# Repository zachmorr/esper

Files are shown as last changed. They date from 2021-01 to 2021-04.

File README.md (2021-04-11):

# This Project has moved!

It can now be [found here](https://github.com/openesper/esper).

This repo is just kept so history is still available

Imgur

# About Esper

Heavily inspired by the [Pi-Hole](https://github.com/pi-hole/pi-hole), this project aims to bring network wide ad-blocking to another popular device popular among makers and hobbyists, the ESP32.

## What is DNS?

Commonly referred to as the "phone book for the internet", the DNS protocol is how devices map human readable urls like google.com or facebook.com into IP addresses that the device can use.

## How does Esper block ads?

Just like the [Pi-Hole](https://github.com/pi-hole/pi-hole), Esper acts as a DNS server for devices. When sent a DNS query, Esper will read the url the device is requesting, then decide to block the request by returning 0.0.0.0 or forward the request on to a real DNS server.

## Differences between Pi-hole and Esper

The biggest, and most obvious difference is the hardware these projects run on. Pi-hole aims to be available on any Linux powered hardware, while Esper is an ESP32 specific project. Due to being run on a microcontroller, Esper is much more limited in it's capabilities and is therefore much more minimal in it's design.

## Why choose Esper instead of Pi-hole?

Choose whatever one suits you! If you like tinkering with hardware, and do not have much experience with the Raspberry Pi/Linux ecosystem, setting up the Esper software on an ESP32 dev board might be an interesting project. And while Esper may not be nearly as powerful as a Raspberry Pi, DNS protocol is very lightweight in nature. Unless you are in a household with 10+ people that are always online you will likely never going to need more computing power than a microcontroller can provide.

At the same time, if you have no problem using a shell and Linux environment, the Pi-hole is a much more feature rich and powerful piece of software that is a joy to use.

## How can I get an Esper?

The easiest way, is to purchase a pre-made one from the Tindie store. (Link incoming...) 

If you have some ESP32 development boards collecting dust, it will work on those too! It will take some slight configuration ([see instructions here](https://github.com/zachmorr/esper/blob/main/software/README.md)), but you can have it running in no time.

DISCLAIMER: It is **heavily** recommended to use a device with ethernet. Even the best Wifi will significantly increase latency and decrease reliability compared to a good copper connection.

If you want to try you hand an making an Esper from scratch, the hardware directory contains all the schematic, pcb, and enclosure files needed to build one yourself.

## Reprogramming Esper

Do you like the Esper hardware, but want to use it for something other than ad-blocking? Great! The Esper hardware is completely reprogrammable and includes an on-board USB-UART converter, no extra programmers are needed!

# Esper Development

## Tools Used

* KiCAD	- EDA tool used to design PCB
* FreeCAD - 3D modeling tool for designing enclosure
* Hugo - Static website generator used for embedded Esper website
* ESP-IDF - Contains ESP32 API and build tools for firmware development
* Python 3.7 - Scripts to glue everything together

## Directory Structure

    ├── hardware                    # Hardware root directory
    │   ├── custom components           # Custom KiCad component files
    │   ├── enclosure                   # FreeCAD project and STL files for enclosure
    │   ├── product                     # KiCad projects for Esper
    │   │   ├── usb-programmable        	# Includes CP2102 for easy usb programming
    │   │   └── jtag-header             	# 10-pin header for JTAG & UART, meant to be used with programmer
    │   └── programmer                  # KiCad project for programmer/debugger
    └── software                    # Software root directory
        ├── default blacklist           # List of URLs that will be blocked by default
        ├── firmware                    # ESP-IDF project that contains all code for Esper
        ├── scripts                     # Scripts used in build process and testing
        ├── tests                       # Scripts used in testing (not started yet)
        └── website                     # Hugo project used to generate website

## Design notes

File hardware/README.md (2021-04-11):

PCB

# Esper Hardware Design

## Goals

All Esper hardware is designed to be as easy to modify and manufacture as possible.

### PCB & Schematic

KiCAD is the obvious choice for EDA since it is free and has a large community support.

### Manufacturing

The Esper device is designed to be manufactured and assembled at JLCPCB. At low quantities (5-10 boards), no other board house that I've found comes close on price and ease of use.

This may change in the future if other companies start matching JLCPCB in price, or if I need to start manufacturing Esper at higher quantities.

### Part Selection

To make the process of manufacturing and assembly as easy as possible, all components (except connectors) are chosen from the [JLCPCB parts library](https://jlcpcb.com/parts). This means that connectors are the only parts that need to be hand soldered, but JLC recently added connectors to their parts library so this may change soon.

Also, in order to minimize the amount of work needed to keep custom schematic symbols and footprints up-to-date, it was a priority to minimize the amount of custom components and only use parts found in the default KiCAD library. Almost every part in the project has footprints and symbols included in KiCAD, or has an equivalent component included.

### Layers

Esper was originally designed to be two layers, but it ended up being far too much routing work for small savings in price so it was changed to be four layers.

### Enclosure

There are many 3D modeling tools out there, to varying degrees of free-ness, but I am not qualified to go over the pros and cons of each. FreeCAD was chosen for this project simply because it seemed to be the most popular open-source program, but I am sure almost any would work.

The enclosure is currently designed to be 3D printed, but alternatives are being looked into.

## BOM

To fully assemble an Esper, these parts are needed:

| Part | Quantity |
| --- | --- |
| Enclosure Top | 1 |
| Enclosure Bottom | 1 |
| Enclosure Dome | 1 |
| Esper PCBA | 1 |
| [Heat-Set Inserts (M2 x 0.4mm) x 2.5mm](https://www.mcmaster.com/catalog/127/3973) | 2 |
| [Screws (M2 x 0.4mm) x 6mm](https://www.mcmaster.com/catalog/127/3251) | 2 |

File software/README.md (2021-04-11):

Esper

# Esper Software

## Installation

### Arduino

At the moment there is no support for the Arduino environment yet, but it is being worked on.

### Requirements

In order to build and flash Esper, you will first need to [install ESP-IDF](https://docs.espressif.com/projects/esp-idf/en/latest/esp32/get-started/#installation-step-by-step) then [set up the environment variables](https://docs.espressif.com/projects/esp-idf/en/latest/esp32/get-started/index.html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).

### Configuration

If you are not using the Esper hardware, you will need to configure the project for your device. To do this, run 

    cd esper/software/firmware
    idf.py menuconfig

Then configure the options under Application Configuration to match your device's capabilities.

### Building & Flashing

After installing ESP-IDF, build and flash your device by running these commands.

    cd esper/software/firmware
    idf.py build
    idf.py -p PORT [-b BAUD] flash

### Monitoring

If logging is enabled in your build, you can monitor the device while it is connected to your PC with this command

    idf.py -p PORT monitor

### Issues

If you have any issues, [this section](https://docs.espressif.com/projects/esp-idf/en/latest/esp32/get-started/index.html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) may be able to help.

### Website & Blacklist

If any changes are made to the website or blacklist in their respective directories, you will have to run the reformat scripts in the Scripts folder in order for the changes to be put into the build.
Examples of running the scripts can be seen in the build.sh script

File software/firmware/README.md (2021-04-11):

# Esper Firmware

This is an ESP-IDF project, written entirely in C. For an explination of the project structure and files, [the espressif docs](https://docs.espressif.com/projects/esp-idf/en/latest/esp32/api-guides/build-system.html) are a good place to start.

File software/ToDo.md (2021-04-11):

## TODO:

### Version 0.1
- Make LED blink when blocking
- Run through tests
- Set up Tindie
    - Packaging?
- How to use guide
- Basic site at openesper.com
- Push to official repo

### Tests:
- Start writing test doc
- Start incorporating unit testing
### Build
- Add Arduino support
### Web
- Password authentication
- Respond to POST requests with current results
- Analytics
    - Total queries and total blocked queries
    - most blocked/queried websites
- show currently connected network & ip
- show connected clients
- Add log page select to homepage 
- Upload/download blacklist files
- advanced settings fold
### Debugging
- Add debug page to website
- Add errors to error log
- remaining memory
    - total and for each task
### OTA Updates
- progress bar
### DATETIME
- Add timezone select
- Connect to SNTP in background, non-blocking
### CONFIGURATION
- Look into wifi_provisioning library
### DNS
- Support for non A/AAAA types
- better client handling
    - print error if client never got response
- Reverse DNS support
- Benchmark DNS response times
### LEDs
- LED Error Codes
### BLACKLIST
- more error handling errors
- Benchmark speed improvement from keeping blacklist in RAM instead of flash
### FLASH
- figure out way to emulate flash wear out & error handling
- Handle flash errors
- Document what is being held in flash

## Maybe Some Day:
- DHCP support
    - Individual block lists for devices
    - User accounts??
- DNS Over HTTPS (early tests dont look hopeful for ESP32, will likely need MPU)

## Known Bugs:
- Logging breaks under high bandwidth (~25 queries per second)
- Throws "emac_esp32: no mem for receive buffer" at high bandwidth 
- Does not respond to queries with 'Additional Sections' (aka dig) correctly
- Does not repond to reverse lookups correctly
- Have to reset device if network ssid/pass change
- black/whitelist buttons on homepage do not update after being added

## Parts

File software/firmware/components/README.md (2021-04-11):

# Directory of all components used in project

### Datetime

Used to get time from SNTP server

### DNS

All DNS related activities are in here. This is where the socket, listening on port 53, is created and then parses any packets it receives.

### Error

This is where the ERROR_CHECK macro, as well as most errors are defined. 

### Events

This component keeps track of the current state of the module using a FreeRTOS event group. 
Any component get set/clear/check any of the event bits at any time.

### Flash

All methods that retreive data from flash are located in this component. It stores blacklist, settings, and logging data to be retreived by other components.

### GPIO

LED and button functions. LED task it notified any time the current state of the device is changed and updates accordingly.

### HTTP

This is the largest component. It stores all the code for both the application and configuration websites.

### Logging

The logging task is in here. The task is notified any time a DNS query is made and then adds it's data to the log file.

### NetIF

Ethernet and Wifi code. Not used much after device is initialized and running.

### OTA

Over-The-Air updates. This contains the tasks that periodically check for updates and then writes the new update to flash.

### URL

Slightly confusing name, this is where the blacklist is kept. All functions that relate to the blacklist as well as url parsing are in here.

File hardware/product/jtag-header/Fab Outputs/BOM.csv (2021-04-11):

Comment | Designator | Footprint | LCSC
1uF | C1,C4,C9 | Capacitor_SMD:C_0402_1005Metric | C52923
10uF | C3,C10 | Capacitor_SMD:C_0805_2012Metric | C15850
0.1uF | C2,C5,C6,C7,C8,C11 | Capacitor_SMD:C_0402_1005Metric | C1525
GRN | D1 | Diode_SMD:D_0603_1608Metric | C72043
RS-3535MWAR | D2 | LED_SMD:LED_RGB_PLCC-6 | C110402
Ferrite_Bead | FB2 | Inductor_SMD:L_0805_2012Metric | C1015
MountingHole | H1,H2 | MountingHole:MountingHole_2.2mm_M2_Pad
USB_B_Micro | J1 | Connector_USB:USB_Micro-B_Molex-105017-0001
Conn_02x05_Odd_Even | J2 | EsperFootprints:CNC_3220-10-0100-00
RJ45_Amphenol_RJMG1BD3B8K1ANR | J3 | Connector_RJ:RJ45_Amphenol_RJMG1BD3B8K1ANR
2N7002 | Q1,Q2,Q3 | Package_TO_SOT_SMD:SOT-23 | C8545
470 | R1 | Resistor_SMD:R_0402_1005Metric | C25117
10K | R2,R8,R10,R11,R12,R24 | Resistor_SMD:R_0402_1005Metric | C25744
270 | R17,R21 | Resistor_SMD:R_0603_1608Metric | C22966
12.1K | R23 | Resistor_SMD:R_0402_1005Metric | C25852
47 | R3,R4 | Resistor_SMD:R_0603_1608Metric | C23182
82 | R5 | Resistor_SMD:R_1206_3216Metric | C247183
49.9 | R6,R7,R9,R13,R14,R15,R16,R18,R19,R20,R22 | Resistor_SMD:R_0402_1005Metric | C25120
PTS645VH83-2 LFS | SW1 | Button_Switch_THT:SW_Tactile_SPST_Angled_PTS645Vx83-2LFS
AZ1117EH-3.3TRG1 | U1 | Package_TO_SOT_SMD:SOT-223 | C108494
ESP32-WROOM-32E | U2 | RF_Module:ESP32-WROOM-32 | C701341
LAN8720A | U3 | Package_DFN_QFN:QFN-24-1EP_4x4mm_P0.5mm_EP2.6x2.6mm_ThermalVias | C45223

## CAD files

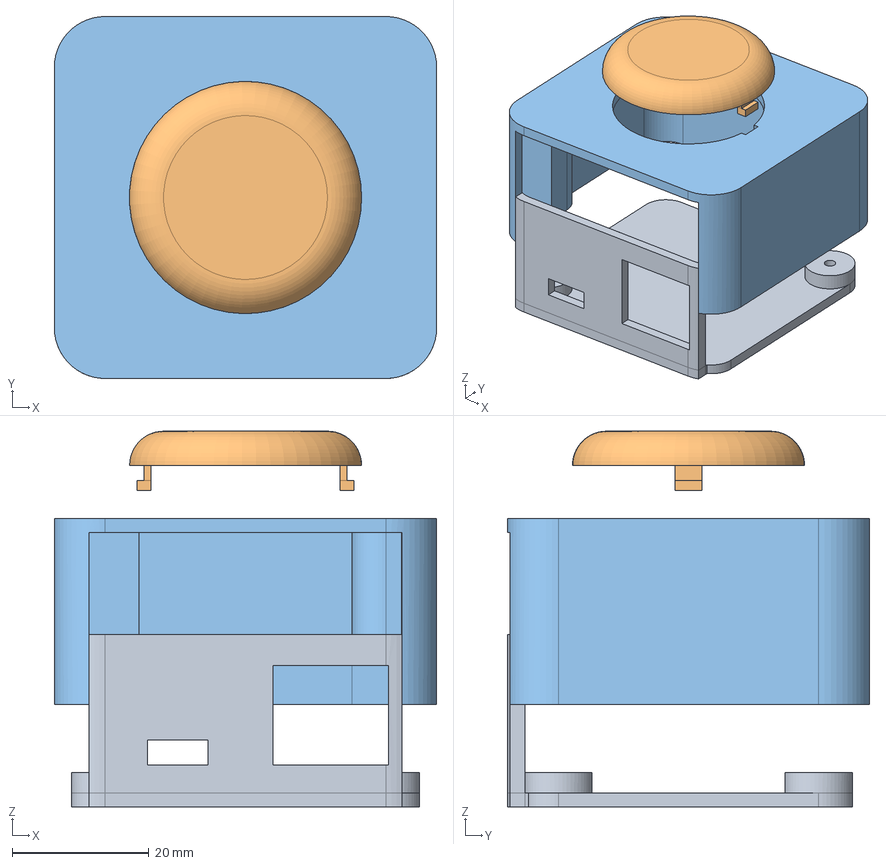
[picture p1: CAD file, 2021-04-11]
hardware/enclosure/Enclosure.FCStd
56.0 x 53.0 x 55.0 mm
Enclosure Bottom
Enclosure Dome
Enclosure Top

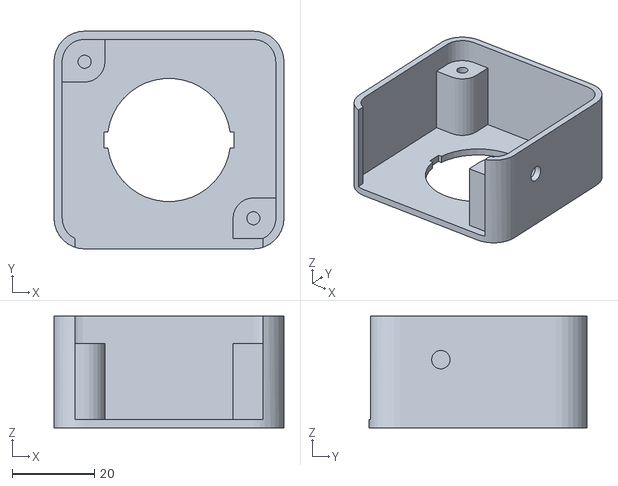
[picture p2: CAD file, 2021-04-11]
hardware/enclosure/EnclosureTop.stl
56.0 x 53.0 x 27.2

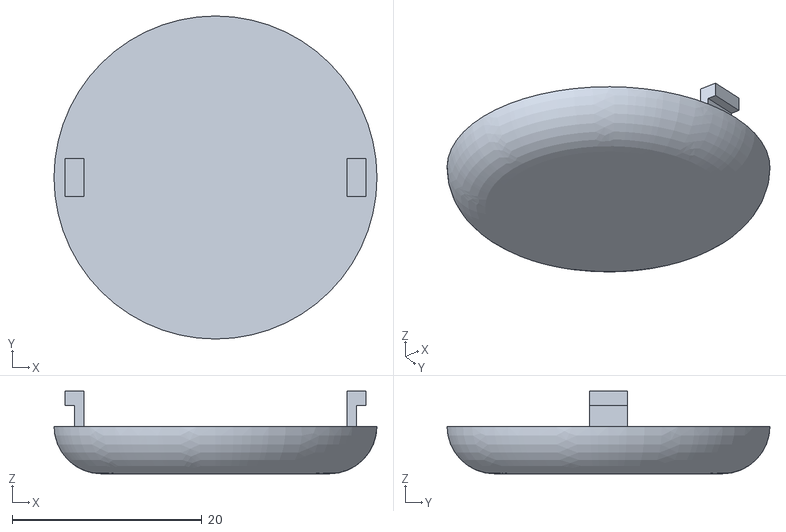
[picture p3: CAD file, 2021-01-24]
hardware/enclosure/EnclosureDome.stl
34.0 x 34.0 x 8.70

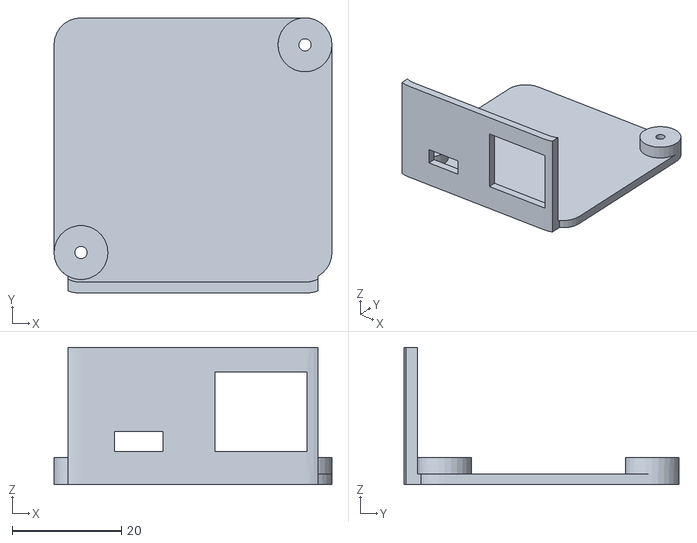
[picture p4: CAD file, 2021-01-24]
hardware/enclosure/EnclosureBottom.stl
51.0 x 50.5 x 25.2

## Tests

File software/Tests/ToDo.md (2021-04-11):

## Tests

### Initialization
1. LED is showing correct color during startup
2. Interfaces are initialized correctly, according to build options
3. Blocklists are successfully loaded in RAM
4. Logging file is opened
5. Webserver is initialized
6. LED is changed after initialization if finished

### Provisioning
1. Skip provisioning if wifi is disabled
2. Scan is started at boot
3. New scan is started when scan button is pressed
4. Error returned if ssid/pass is invalid
5. Connection successful if ssid/pass is valid
6. Ethernet saves IP if wifi is disabled and provisioning is skipped
7. Correct LED color is shown during provisioning

### Startup
1. Time is correctly received via SNTP 
2. Sockets created and listening on port 53
3. Webserver changes from provisioning to application correctly
4. Successfully checks for update at startup

### SNTP
1. Gets time from server and saves it to memory
2. Sets time to default value if SNTP server cant be reached
    - Continue to poll server if it fails
3. Changing timezone successfully updates current time

### DNS
1. Socket is created and listens for UDP packets on port 53
2. Packets larger than 512 bytes do not cause error
3. All DNS packets are forwarded if blocking is turned off
4. Packets that are not 'A' or 'AAAA' are forwarded
5. Responses from DNS server are successfully forward to correct client
6. DNS packets are 'blocked' if qname is in blacklist
7. DNS packets are 'captured' if provisioning is enabled or is qname matches device url

### GPIO
1. LEDs turn on and are correct colors
2. Pressing button toggles blocking state
3. Holding button for 5 seconds resets device
4. Holding button for 10 seconds rolls back to previous version

### Logging
1. DNS packets are logged successfully

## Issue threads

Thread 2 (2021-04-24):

lan8720: lan8720_init(411): wrong chip ID

gustavo-luz, 2021-04-24:
Was getting this error:
```
CMake Error at run_serial_tool.cmake:50 (message):
  /home/gustavo/.espressif/python_env/idf4.4_py3.8_env/bin/python
  /home/gustavo/esp/esp-idf/components/esptool_py/esptool/esptool.py --chip
  esp32 failed

make[3]: *** [CMakeFiles/flash.dir/build.make:57: CMakeFiles/flash] Error 1
make[2]: *** [CMakeFiles/Makefile2:2266: CMakeFiles/flash.dir/all] Error 2
make[1]: *** [CMakeFiles/Makefile2:2273: CMakeFiles/flash.dir/rule] Error 2
make: *** [Makefile:203: flash] Error 2
make failed with exit code 2
```
then i ran ```sudo chmod -R 777 /dev/ttyUSB0``` and was able to flash and write with no problems.

after that i started to have the following error at final step of   ```idf.py -p /dev/ttyUSB0 monitor```

```
E (851) lan8720: lan8720_init(411): wrong chip ID
E (851) esp_eth: esp_eth_driver_install(196): init phy failed
E (851) ETH: esp_eth_driver_install(&config, eth_handle) (ESP_FAIL)(FFFFFFFF)
E (851) IP: init_eth_handle(&eth_handle) (ESP_FAIL)(FFFFFFFF)
E (861) APP_BOOT: initialize_interfaces() (ESP_FAIL)(FFFFFFFF)
I (871) APP_BOOT: Starting provisioning...
I (871) IP: Turning Accesspoint on
E (881) IP: esp_wifi_set_mode(WIFI_MODE_APSTA) (ESP_ERR_WIFI_NOT_INIT)(3001)
E (881) APP_BOOT: turn_on_accesspoint() (ESP_FAIL)(FFFFFFFF)
I (891) APP_BOOT: Starting application...
I (891) IP: Starting interfaces
E (901) esp_eth: esp_eth_start(254): ethernet driver handle can't be null
E (911) IP: esp_eth_start(eth_handle) (ESP_ERR_INVALID_ARG)(102)
E (911) APP_BOOT: start_interfaces() (ESP_FAIL)(FFFFFFFF)
```

any clues ?

zachmorr, 2021-04-24:
What hardware is this on? Are you using a board with Ethernet? The lan8720 is an ethernet PHY, so if you are using a different PHY or no PHY you may get this error.

zachmorr, 2021-04-24:
If you are using a board without Ethernet, try disabling Ethernet in menuconfig, under application settings. Then run idf.py erase_flash; idf.py flash monitor;

gustavo-luz, 2021-04-25:
Its on nodemcu espwroom32, no ethernet. will try that, thanks

Closed 2021-04-28.

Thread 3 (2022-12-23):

Failed to resolve component 'littlefs' while running idf menuconfig or build commands

syedautherabbas, 2022-12-23:
syed@syeds-ubuntu:~/pihole/esper/software/firmware$ idf.py erase-flash
Executing action: erase-flash
Running cmake in directory /home/syed/pihole/esper/software/firmware/build
Executing "cmake -G Ninja -DPYTHON_DEPS_CHECKED=1 -DESP_PLATFORM=1 -DCCACHE_ENABLE=0 /home/syed/pihole/esper/software/firmware"...
-- IDF_TARGET not set, using default target: esp32
-- Found Git: /usr/bin/git (found version "2.37.2")
-- Component directory /home/syed/pihole/esper/software/firmware/components/littlefs does not contain a CMakeLists.txt file. No component will be added
-- The C compiler identification is GNU 8.4.0
-- The CXX compiler identification is GNU 8.4.0
-- The ASM compiler identification is GNU
-- Found assembler: /home/syed/.espressif/tools/xtensa-esp32-elf/esp-2021r2-8.4.0/xtensa-esp32-elf/bin/xtensa-esp32-elf-gcc
-- Detecting C compiler ABI info
-- Detecting C compiler ABI info - done
-- Check for working C compiler: /home/syed/.espressif/tools/xtensa-esp32-elf/esp-2021r2-8.4.0/xtensa-esp32-elf/bin/xtensa-esp32-elf-gcc - skipped
-- Detecting C compile features
-- Detecting C compile features - done
-- Detecting CXX compiler ABI info
-- Detecting CXX compiler ABI info - done
-- Check for working CXX compiler: /home/syed/.espressif/tools/xtensa-esp32-elf/esp-2021r2-8.4.0/xtensa-esp32-elf/bin/xtensa-esp32-elf-g++ - skipped
-- Detecting CXX compile features
-- Detecting CXX compile features - done
-- Building ESP-IDF components for target esp32
CMake Error at /home/syed/matter/tools/esp-idf/tools/cmake/build.cmake:200 (message):
  Failed to resolve component 'littlefs'.
Call Stack (most recent call first):
  /home/syed/matter/tools/esp-idf/tools/cmake/build.cmake:231 (__build_resolve_and_add_req)
  /home/syed/matter/tools/esp-idf/tools/cmake/build.cmake:232 (__build_expand_requirements)
  /home/syed/matter/tools/esp-idf/tools/cmake/build.cmake:232 (__build_expand_requirements)
  /home/syed/matter/tools/esp-idf/tools/cmake/build.cmake:512 (__build_expand_requirements)
  /home/syed/matter/tools/esp-idf/tools/cmake/project.cmake:378 (idf_build_process)
  CMakeLists.txt:8 (project)

abejfehr, 2022-12-29:
This happened to me, the components/littlefs folder was empty so I had to `git submodule update --init` in it

rBazan98, 2023-09-06:
> This happened to me, the components/littlefs folder was empty so I had to `git submodule update --init` in it

I had the same problem too. The components/littlefs directory contains yet another "commit-referenced" folder, components/littlefs/src/littlefs, so you need to run `git submodule update --init --recursive`

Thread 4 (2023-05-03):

Errors and warnings while building the project

NatDevzl, 2023-05-03:
When building the project, I encounter the following errors and warnings:

Executing action: all (aliases: build)
Running ninja in directory c:\users\nat\documents\esper\software\firmware\build
Executing "ninja all"...
[57/903] Generating ../../partition_table/partition-table.binPartition table binary generated. Contents:
*******************************************************************************
# ESP-IDF Partition Table
# Name, Type, SubType, Offset, Size, Flags
nvs,data,nvs,0x9000,16K,
otadata,data,ota,0xd000,8K,
phy_init,data,phy,0xf000,4K,
ota_0,app,ota_0,0x10000,1152K,
ota_1,app,ota_1,0x130000,1152K,
spiffs,data,spiffs,0x250000,1728K,
*******************************************************************************
[846/903] Building C object esp-idf/littlefs/CMakeFiles/__idf_littlefs.dir/src/littlefs_api.c.objFAILED: esp-idf/littlefs/CMakeFiles/__idf_littlefs.dir/src/littlefs_api.c.obj
ccache C:\Users\Nat\.espressif\tools\xtensa-esp32-elf\esp-2022r1-11.2.0\xtensa-esp32-elf\bin\xtensa-esp32-elf-gcc.exe  -IC:/Users/Nat/Documents/esper/software/firmware/build/config -IC:/Users/Nat/Documents/esper/software/firmware/components/littlefs/src -IC:/Users/Nat/Documents/esper/software/firmware/components/littlefs/include -IC:/Users/Nat/esp/components/newlib/platform_include -IC:/Users/Nat/esp/components/freertos/FreeRTOS-Kernel/include -IC:/Users/Nat/esp/components/freertos/esp_additions/include/freertos -IC:/Users/Nat/esp/components/freertos/FreeRTOS-Kernel/portable/xtensa/include -IC:/Users/Nat/esp/components/freertos/esp_additions/include -IC:/Users/Nat/esp/components/esp_hw_support/include -IC:/Users/Nat/esp/components/esp_hw_support/include/soc -IC:/Users/Nat/esp/components/esp_hw_support/include/soc/esp32 -IC:/Users/Nat/esp/components/esp_hw_support/port/esp32/. -IC:/Users/Nat/esp/components/esp_hw_support/port/esp32/private_include -IC:/Users/Nat/esp/components/heap/include -IC:/Users/Nat/esp/components/log/include -IC:/Users/Nat/esp/components/soc/include -IC:/Users/Nat/esp/components/soc/esp32/. -IC:/Users/Nat/esp/components/soc/esp32/include -IC:/Users/Nat/esp/components/hal/esp32/include -IC:/Users/Nat/esp/components/hal/include -IC:/Users/Nat/esp/components/hal/platform_port/include -IC:/Users/Nat/esp/components/esp_rom/include -IC:/Users/Nat/esp/components/esp_rom/include/esp32 -IC:/Users/Nat/esp/components/esp_rom/esp32 -IC:/Users/Nat/esp/components/esp_common/include -IC:/Users/Nat/esp/components/esp_system/include -IC:/Users/Nat/esp/components/esp_system/port/soc -IC:/Users/Nat/esp/components/esp_system/port/include/private -IC:/Users/Nat/esp/components/xtensa/include -IC:/Users/Nat/esp/components/xtensa/esp32/include -IC:/Users/Nat/esp/components/lwip/include -IC:/Users/Nat/esp/components/lwip/include/apps -IC:/Users/Nat/esp/components/lwip/include/apps/sntp -IC:/Users/Nat/esp/components/lwip/lwip/src/include -IC:/Users/Nat/esp/components/lwip/port/esp32/include -IC:/Users/Nat/esp/components/lwip/port/esp32/include/arch -IC:/Users/Nat/esp/components/spi_flash/include -mlongcalls -Wno-frame-address  -fdiagnostics-color=always -ffunction-sections -fdata-sections -Wall -Werror=all -Wno-error=unused-function -Wno-error=unused-variable -Wno-error=deprecated-declarations -Wextra -Wno-unused-parameter -Wno-sign-compare -Wno-enum-conversion -gdwarf-4 -ggdb -Og -fmacro-prefix-map=C:/Users/Nat/Documents/esper/software/firmware=. -fmacro-prefix-map=C:/Users/Nat/esp=/IDF -fstrict-volatile-bitfields -Wno-error=unused-but-set-variable -fno-jump-tables -fno-tree-switch-conversion -DconfigENABLE_FREERTOS_DEBUG_OCDAWARE=1 -std=gnu17 -Wno-old-style-declaration -D_GNU_SOURCE -DIDF_VER=\"v5.0.1\" -DESP_PLATFORM -D_POSIX_READER_WRITER_LOCKS -MD -MT esp-idf/littlefs/CMakeFiles/__idf_littlefs.dir/src/littlefs_api.c.obj -MF esp-idf\littlefs\CMakeFiles\__idf_littlefs.dir\src\littlefs_api.c.obj.d -o esp-idf/littlefs/CMakeFiles/__idf_littlefs.dir/src/littlefs_api.c.obj -c C:/Users/Nat/Documents/esper/software/firmware/components/littlefs/src/littlefs_api.c
C:/Users/Nat/Documents/esper/software/firmware/components/littlefs/src/littlefs_api.c:10:10: fatal error: esp_partition.h: No such file or directory
   10 | #include "esp_partition.h"
      |          ^~~~~~~~~~~~~~~~~
compilation terminated.
[847/903] Performing configure step for 'bootloader'-- Building ESP-IDF components for target esp32
-- Project sdkconfig file C:/Users/Nat/Documents/esper/software/firmware/sdkconfig
-- Adding linker script C:/Users/Nat/esp/components/soc/esp32/ld/esp32.peripherals.ld
-- App "bootloader" version: v5.0.1
-- Adding linker script C:/Users/Nat/esp/components/esp_rom/esp32/ld/esp32.rom.ld
-- Adding linker script C:/Users/Nat/esp/components/esp_rom/esp32/ld/esp32.rom.api.ld
-- Adding linker script C:/Users/Nat/esp/components/esp_rom/esp32/ld/esp32.rom.libgcc.ld
-- Adding linker script C:/Users/Nat/esp/components/esp_rom/esp32/ld/esp32.rom.newlib-funcs.ld
-- Adding linker script C:/Users/Nat/esp/components/bootloader/subproject/main/ld/esp32/bootloader.ld
-- Adding linker script C:/Users/Nat/esp/components/bootloader/subproject/main/ld/esp32/bootloader.rom.ld
-- Components: bootloader bootloader_support efuse esp_app_format esp_common esp_hw_support esp_rom esp_system esptool_py freertos hal log main micro-ecc newlib partition_table soc spi_flash xtensa
-- Component paths: C:/Users/Nat/esp/components/bootloader C:/Users/Nat/esp/components/bootloader_support C:/Users/Nat/esp/components/efuse C:/Users/Nat/esp/components/esp_app_format C:/Users/Nat/esp/components/esp_common C:/Users/Nat/esp/components/esp_hw_support C:/Users/Nat/esp/components/esp_rom C:/Users/Nat/esp/components/esp_system C:/Users/Nat/esp/components/esptool_py C:/Users/Nat/esp/components/freertos C:/Users/Nat/esp/components/hal C:/Users/Nat/esp/components/log C:/Users/Nat/esp/components/bootloader/subproject/main C:/Users/Nat/esp/components/bootloader/subproject/components/micro-ecc C:/Users/Nat/esp/components/newlib C:/Users/Nat/esp/components/partition_table C:/Users/Nat/esp/components/soc C:/Users/Nat/esp/components/spi_flash C:/Users/Nat/esp/components/xtensa
-- Configuring done
-- Generating done
-- Build files have been written to: C:/Users/Nat/Documents/esper/software/firmware/build/bootloader
[848/903] Building C object esp-idf/littlefs/CMakeFiles/__idf_littlefs.dir/src/esp_littlefs.c.objFAILED: esp-idf/littlefs/CMakeFiles/__idf_littlefs.dir/src/esp_littlefs.c.obj
ccache C:\Users\Nat\.espressif\tools\xtensa-esp32-elf\esp-2022r1-11.2.0\xtensa-esp32-elf\bin\xtensa-esp32-elf-gcc.exe  -IC:/Users/Nat/Documents/esper/software/firmware/build/config -IC:/Users/Nat/Documents/esper/software/firmware/components/littlefs/src -IC:/Users/Nat/Documents/esper/software/firmware/components/littlefs/include -IC:/Users/Nat/esp/components/newlib/platform_include -IC:/Users/Nat/esp/components/freertos/FreeRTOS-Kernel/include -IC:/Users/Nat/esp/components/freertos/esp_additions/include/freertos -IC:/Users/Nat/esp/components/freertos/FreeRTOS-Kernel/portable/xtensa/include -IC:/Users/Nat/esp/components/freertos/esp_additions/include -IC:/Users/Nat/esp/components/esp_hw_support/include -IC:/Users/Nat/esp/components/esp_hw_support/include/soc -IC:/Users/Nat/esp/components/esp_hw_support/include/soc/esp32 -IC:/Users/Nat/esp/components/esp_hw_support/port/esp32/. -IC:/Users/Nat/esp/components/esp_hw_support/port/esp32/private_include -IC:/Users/Nat/esp/components/heap/include -IC:/Users/Nat/esp/components/log/include -IC:/Users/Nat/esp/components/soc/include -IC:/Users/Nat/esp/components/soc/esp32/. -IC:/Users/Nat/esp/components/soc/esp32/include -IC:/Users/Nat/esp/components/hal/esp32/include -IC:/Users/Nat/esp/components/hal/include -IC:/Users/Nat/esp/components/hal/platform_port/include -IC:/Users/Nat/esp/components/esp_rom/include -IC:/Users/Nat/esp/components/esp_rom/include/esp32 -IC:/Users/Nat/esp/components/esp_rom/esp32 -IC:/Users/Nat/esp/components/esp_common/include -IC:/Users/Nat/esp/components/esp_system/include -IC:/Users/Nat/esp/components/esp_system/port/soc -IC:/Users/Nat/esp/components/esp_system/port/include/private -IC:/Users/Nat/esp/components/xtensa/include -IC:/Users/Nat/esp/components/xtensa/esp32/include -IC:/Users/Nat/esp/components/lwip/include -IC:/Users/Nat/esp/components/lwip/include/apps -IC:/Users/Nat/esp/components/lwip/include/apps/sntp -IC:/Users/Nat/esp/components/lwip/lwip/src/include -IC:/Users/Nat/esp/components/lwip/port/esp32/include -IC:/Users/Nat/esp/components/lwip/port/esp32/include/arch -IC:/Users/Nat/esp/components/spi_flash/include -mlongcalls -Wno-frame-address  -fdiagnostics-color=always -ffunction-sections -fdata-sections -Wall -Werror=all -Wno-error=unused-function -Wno-error=unused-variable -Wno-error=deprecated-declarations -Wextra -Wno-unused-parameter -Wno-sign-compare -Wno-enum-conversion -gdwarf-4 -ggdb -Og -fmacro-prefix-map=C:/Users/Nat/Documents/esper/software/firmware=. -fmacro-prefix-map=C:/Users/Nat/esp=/IDF -fstrict-volatile-bitfields -Wno-error=unused-but-set-variable -fno-jump-tables -fno-tree-switch-conversion -DconfigENABLE_FREERTOS_DEBUG_OCDAWARE=1 -std=gnu17 -Wno-old-style-declaration -D_GNU_SOURCE -DIDF_VER=\"v5.0.1\" -DESP_PLATFORM -D_POSIX_READER_WRITER_LOCKS -MD -MT esp-idf/littlefs/CMakeFiles/__idf_littlefs.dir/src/esp_littlefs.c.obj -MF esp-idf\littlefs\CMakeFiles\__idf_littlefs.dir\src\esp_littlefs.c.obj.d -o esp-idf/littlefs/CMakeFiles/__idf_littlefs.dir/src/esp_littlefs.c.obj -c C:/Users/Nat/Documents/esper/software/firmware/components/littlefs/src/esp_littlefs.c
In file included from C:/Users/Nat/Documents/esper/software/firmware/components/littlefs/src/esp_littlefs.c:10:
C:/Users/Nat/esp/components/spi_flash/include/esp_spi_flash.h:6:2: warning: #warning esp_spi_flash.h is deprecated, please use spi_flash_mmap.h instead [-Wcpp]
    6 | #warning esp_spi_flash.h is deprecated, please use spi_flash_mmap.h instead
      |  ^~~~~~~
In file included from C:/Users/Nat/Documents/esper/software/firmware/components/littlefs/src/esp_littlefs.c:24:
C:/Users/Nat/Documents/esper/software/firmware/components/littlefs/src/littlefs_api.h:9:10: fatal error: esp_vfs.h: No such file or directory
    9 | #include "esp_vfs.h"
      |          ^~~~~~~~~~~
compilation terminated.
[849/903] Building CXX object esp-idf/dns/CMakeFiles/__idf_dns.dir/server.cpp.objFAILED: esp-idf/dns/CMakeFiles/__idf_dns.dir/server.cpp.obj
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

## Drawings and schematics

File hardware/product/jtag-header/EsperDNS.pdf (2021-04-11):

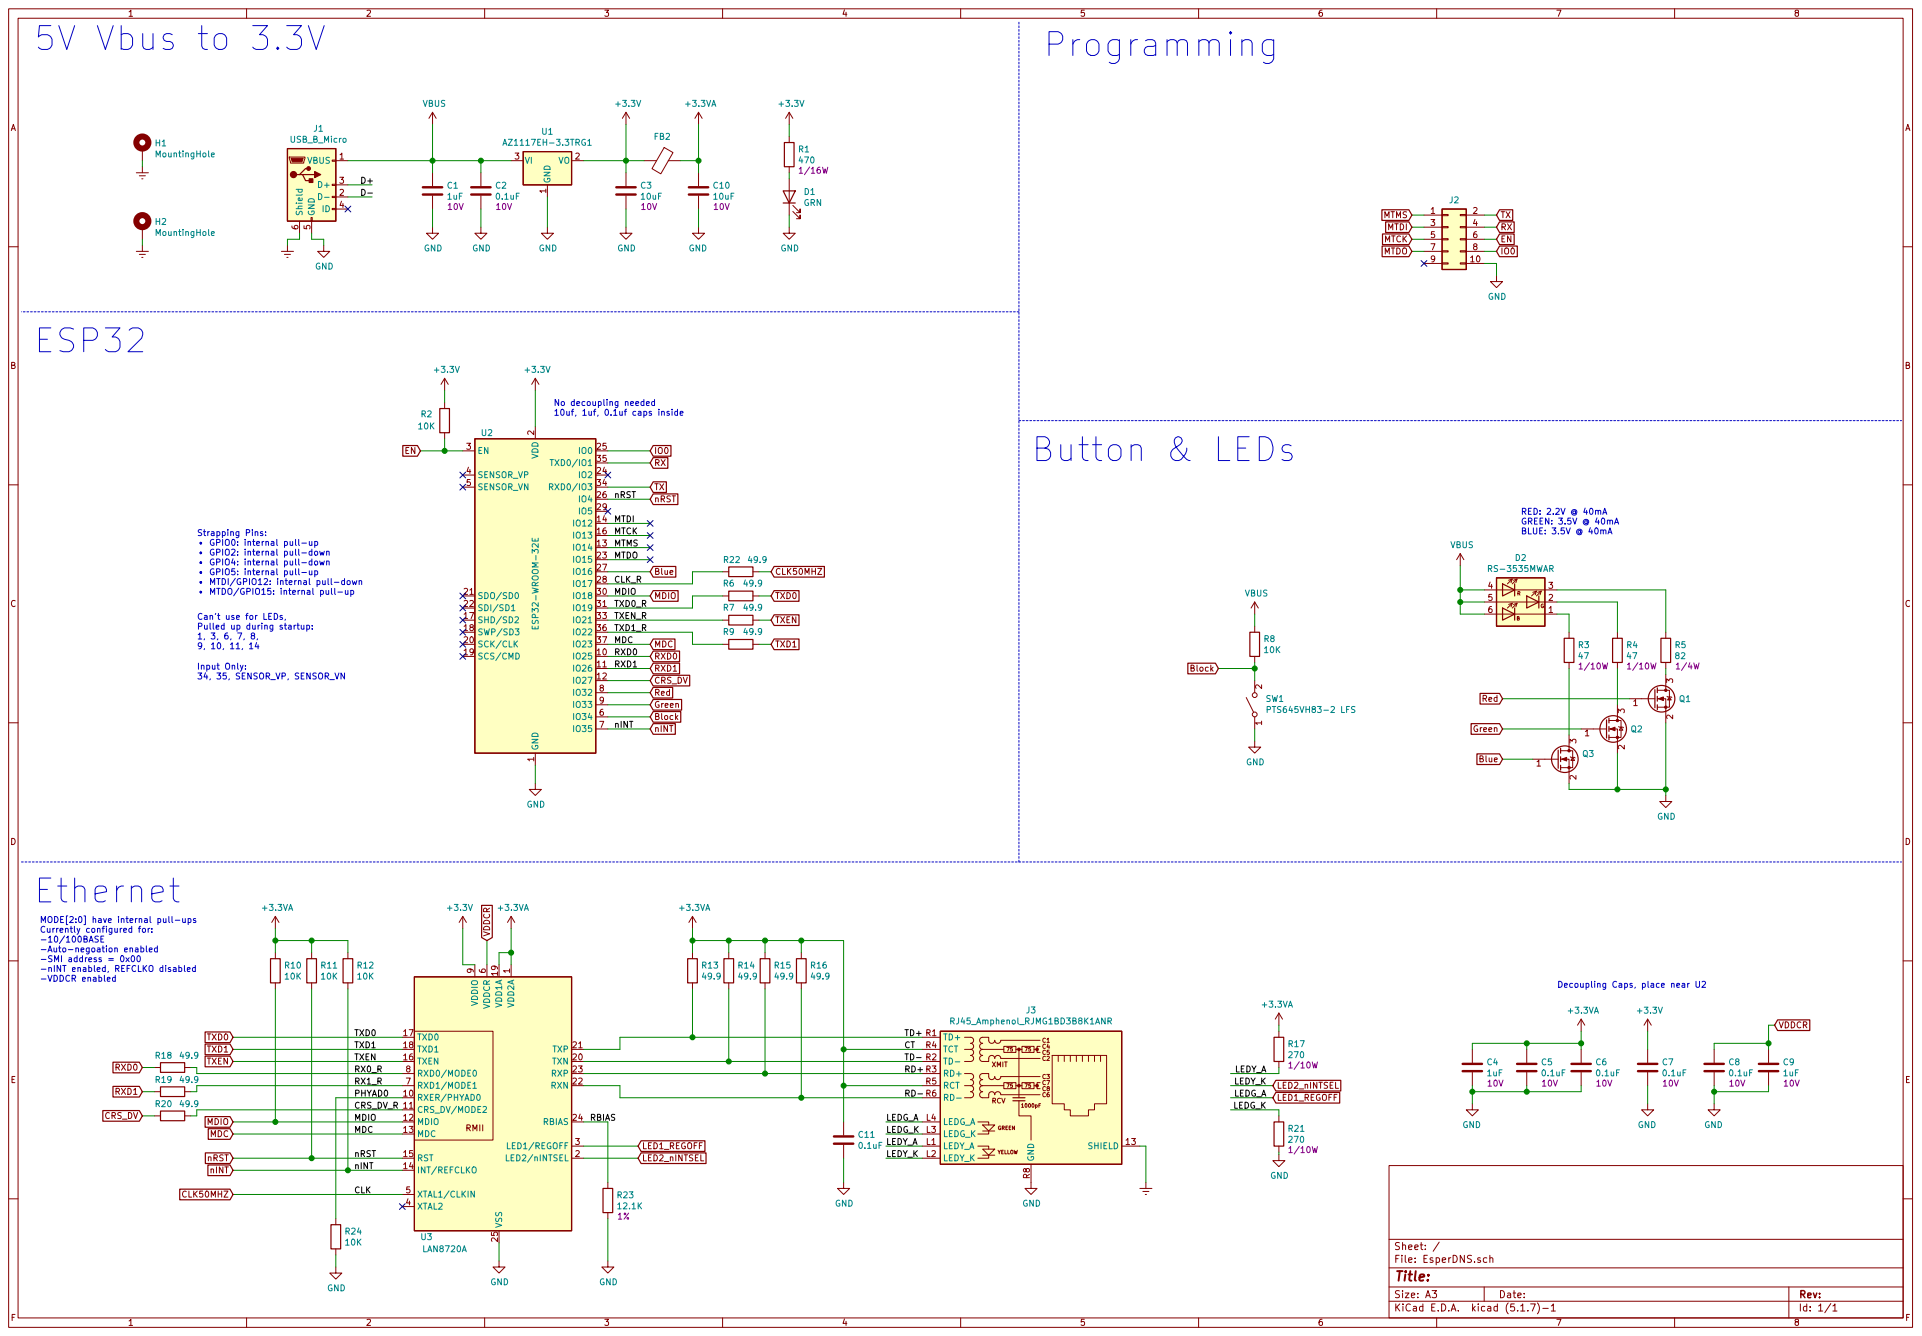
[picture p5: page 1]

1 VO 2 VI 3 U1 AZ1117EH-3.3TRG1 GND GND

2 SCK/CLK 20 SDO/SD0 21 SDI/SD1 22

GPIO0: internal pull-up
GPIO2: internal pull-down
GPIO4: internal pull-down
GPIO5: internal pull-up
MTDI/GPIO12: internal pull-down
MTDO/GPIO15: internal pull-up

Block nRST CLK50MHZ MDIO MDC

MODE[2:0] have internal pull-ups
Currently configured for: -10/100BASE

-Auto-negoation enabled
-SMI address = 0x00
-nINT enabled, REFCLKO disabled

TD- TD+ RD- nRST
nINT PHYAD0
CRS_DV_R
CLK MDIO MDC

File: EsperDNS.sch Sheet: /

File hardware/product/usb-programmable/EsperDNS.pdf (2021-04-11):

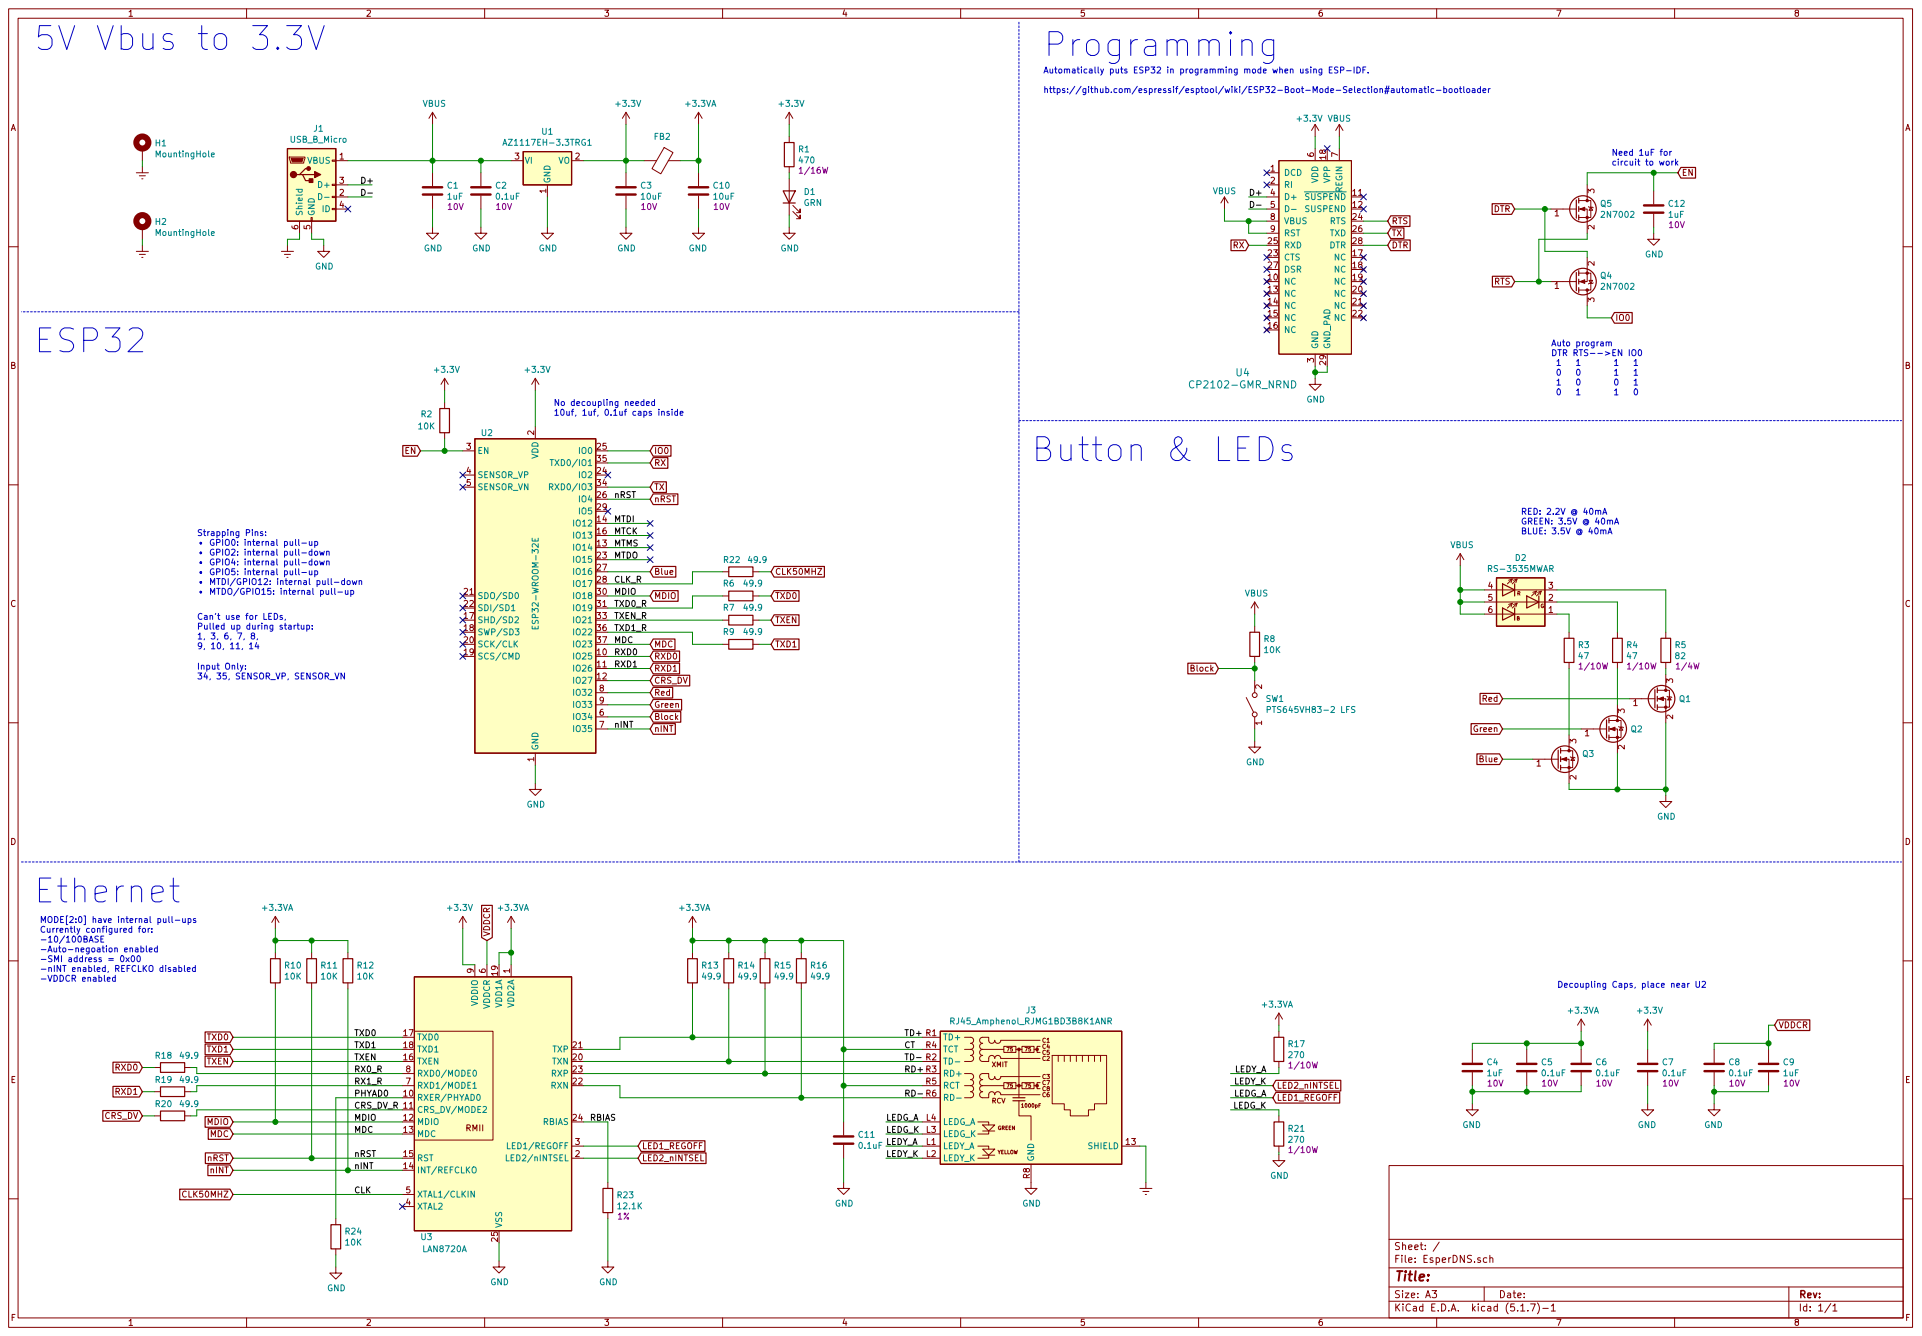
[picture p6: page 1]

-VDDCR enabled 5V Vbus to 3.3V

Automatically puts ESP32 in programming mode when using ESP-IDF.

https://github.com/espressif/esptool/wiki/ESP32-Boot-Mode-Selection#automatic-bootloader

1 VO 2 VI 3 U1 AZ1117EH-3.3TRG1 VBUS GND

Need 1uF for circuit to work ESP32

7 VBUS 8 RST 9 NC 10 NC 20 SUSPEND 11 NC 21 SUSPEND 12 NC 22 NC 13 CTS 23 NC 14 RTS 24 NC 15 RXD 25 NC 16 TXD 26 NC 17 DSR 27 NC 18 VPP 18 DTR 28 NC 19 GND_PAD 29 U4 CP2102-GMR_NRND

nRST MDC MDIO
MTDO MTMS MTCK MTDI CLK_R

2 SCK/CLK 20 SDO/SD0 21 SDI/SD1 22

BLUE: 3.5V @ 40mA MODE[2:0] have internal pull-ups

Strapping Pins:
GPIO0: internal pull-up
GPIO2: internal pull-down
GPIO4: internal pull-down
GPIO5: internal pull-up
MTDI/GPIO12: internal pull-down
MTDO/GPIO15: internal pull-up

-Auto-negoation enabled
-SMI address = 0x00
-nINT enabled, REFCLKO disabled

Decoupling Caps, place near U2

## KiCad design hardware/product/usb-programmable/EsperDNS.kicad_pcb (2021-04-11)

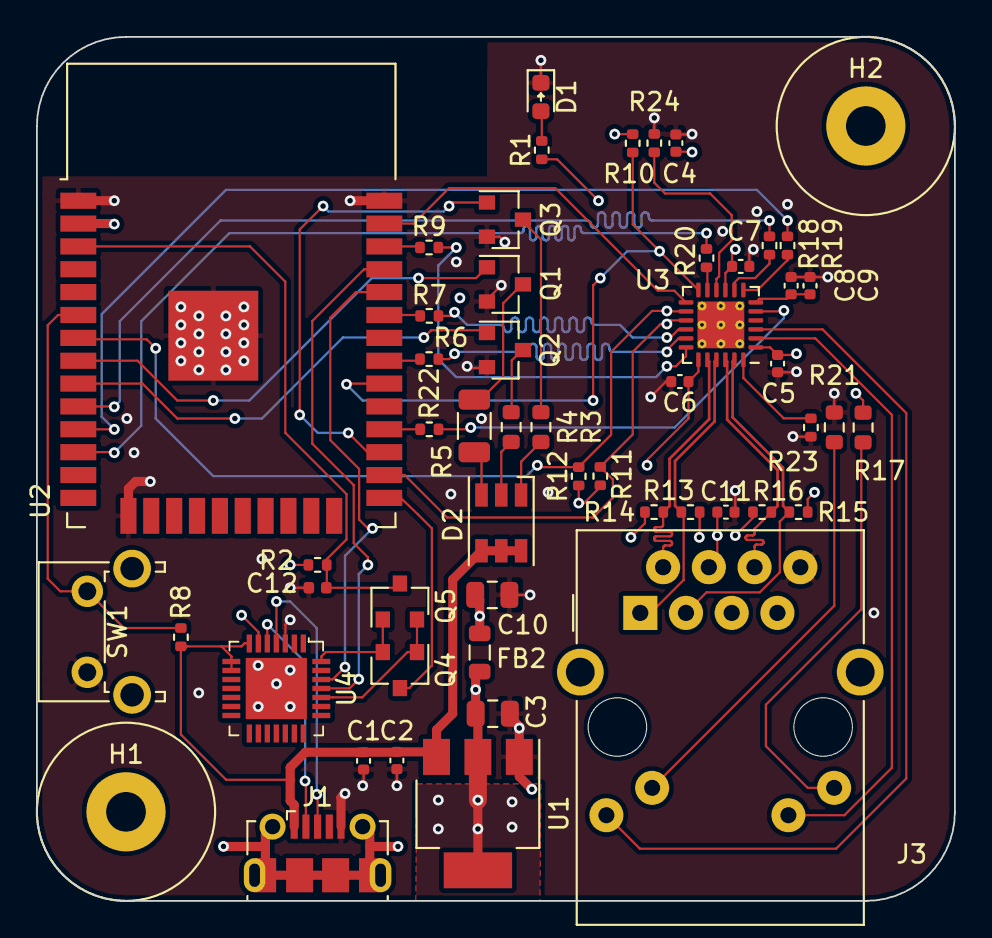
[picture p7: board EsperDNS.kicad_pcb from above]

Board: 4 copper layers, 51.0 x 48.0 mm, 53 parts (0 on the bottom side), 53 nets.

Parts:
C1, C4, C9, C12: 1uF; C_0402_1005Metric
C2, C5, C6, C7, C8, C11: 0.1uF; C_0402_1005Metric
C3, C10: 10uF; C_0805_2012Metric
D1: GRN; D_0603_1608Metric
D2: RS-3535MWAR; LED_RGB_PLCC-6
FB2: Ferrite_Bead; L_0805_2012Metric
H1, H2: MountingHole; MountingHole_2.2mm_M2_Pad
J1: USB_B_Micro; USB_Micro-B_Molex-105017-0001
J3: RJ45_Amphenol_RJMG1BD3B8K1ANR
Q1, Q2, Q3, Q4, Q5: 2N7002; SOT-23
R1: 470; R_0402_1005Metric
R2, R8, R10, R11, R12, R24: 10K; R_0402_1005Metric
R3, R4: 47; R_0603_1608Metric
R5: 82; R_1206_3216Metric
R6, R7, R9, R13, R14, R15, R16, R18, R19, R20, R22: 49.9; R_0402_1005Metric
R17, R21: 270; R_0603_1608Metric
R23: 12.1K; R_0402_1005Metric
SW1: PTS645VH83-2 LFS; SW_Tactile_SPST_Angled_PTS645Vx83-2LFS
U1: AZ1117EH-3.3TRG1; SOT-223
U2: ESP32-WROOM-32E; ESP32-WROOM-32
U3: LAN8720A; QFN-24-1EP_4x4mm_P0.5mm_EP2.6x2.6mm_ThermalVias
U4: CP2102-GMR_NRND; VFQFN-28-1EP_5x5mm

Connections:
+3.3VA: C4.1, C5.1, C6.1, C10.1, C11.1, FB2.1, J3.R4, J3.R5, R10.1, R11.1, R12.1, R13.1, R14.1, R15.1, R16.1, R17.1, U3.1, U3.19
+3V3: C3.1, C7.1, FB2.2, R1.1, R2.2, U1.2, U2.2, U3.9, U4.6
/CLK_R: R22.2, U2.28
/CRS_DV_R: R20.1, U3.11
/D+: J1.3, U4.4
/D-: J1.2, U4.5
/LEDG_K: J3.L3, R21.1
/LEDY_A: J3.L1, R17.2
/PHYAD0: R24.1, U3.10
/RBIAS: R23.1, U3.24
/RD+: J3.R3, R15.2, U3.23
/RD-: J3.R6, R16.2, U3.22
/RX0_R: R18.1, U3.8
/RX1_R: R19.1, U3.7
/TD+: J3.R1, R13.2, U3.21
/TD-: J3.R2, R14.2, U3.20
/TXD0_R: R6.1, U2.31
/TXD1_R: R9.1, U2.36
/TXEN_R: R7.1, U2.33
Block: R8.2, SW1.2, U2.6
Blue: Q3.1, U2.27
CLK50MHZ: R22.1, U3.5
CRS_DV: R20.2, U2.12
DTR: Q4.2, Q5.1, U4.28
EN: C12.1, Q5.3, R2.1, U2.3
Earth: H1.1, H2.1, J1.6, J3.13
GND: C1.2, C2.2, C3.2, C4.2, C5.2, C6.2, C7.2, C8.2, C9.2, C10.2, C11.2, C12.2, D1.1, J1.5, J3.R8, Q1.2, Q2.2, Q3.2, R21.2, R23.2, R24.2, SW1.1, U1.1, U2.1, U2.15, U2.38, U2.39, U3.25, U4.3, U4.29
Green: Q2.1, U2.9
IO0: Q4.3, U2.25
LED1_REGOFF: J3.L4, U3.3
LED2_nINTSEL: J3.L2, U3.2
MDC: U2.37, U3.13
MDIO: R10.2, U2.30, U3.12
unnamed: D1.2, R1.2
unnamed: D2.1, R3.1
unnamed: D2.2, R4.1
unnamed: D2.3, R5.1
unnamed: Q1.3, R5.2
unnamed: Q2.3, R4.2
unnamed: Q3.3, R3.2
RTS: Q4.1, Q5.2, U4.24
RX: U2.35, U4.25
RXD0: R18.2, U2.10
RXD1: R19.2, U2.11
Red: Q1.1, U2.8
TX: U2.34, U4.26
TXD0: R6.2, U3.17
TXD1: R9.2, U3.18
TXEN: R7.2, U3.16
VBUS: C1.1, C2.1, D2.4, D2.5, D2.6, J1.1, R8.1, U1.3, U4.7, U4.8, U4.9
VDDCR: C8.1, C9.1, U3.6
nINT: R12.2, U2.7, U3.14
nRST: R11.2, U2.26, U3.15

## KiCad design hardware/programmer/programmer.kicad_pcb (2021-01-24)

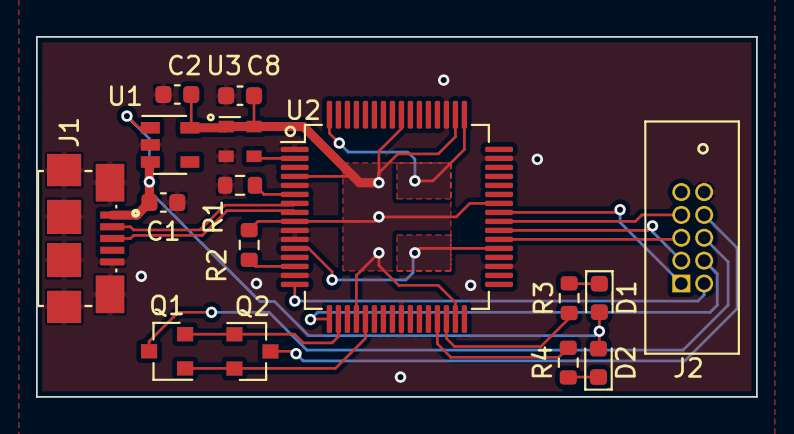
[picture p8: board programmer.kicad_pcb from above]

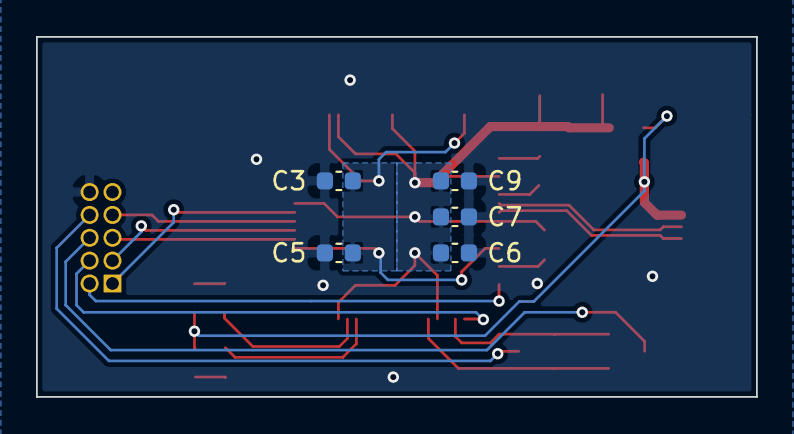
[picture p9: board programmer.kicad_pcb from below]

Board: 2 copper layers, 40.0 x 20.0 mm, 21 parts (5 on the bottom side), 23 nets.

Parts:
C1, C2, C5, C6, C7, C8, C9: 0.1uF; C_0603_1608Metric
C3: 1uF; C_0603_1608Metric
D1: BLU; LED_0603_1608Metric
D2: GRN; LED_0603_1608Metric
J1: 10118192-0001LF; AMPHENOL_10118192-0001LF
J2: 3220-10-0100-00; CNC_3220-10-0100-00
Q1, Q2: 2N7002ET1G; SOT-23
R1, R2: 12K; R_0603_1608Metric
R3, R4: 470; R_0603_1608Metric
U1: TLV75533PDBV; SOT-23-5
U2: FT2232HL; LQFP-64_10x10mm_P0.5mm
U3: ASDMB-12.000MHz; Oscillator_SMD_Abracon_ASDMB-4Pin_2.5x2.0mm

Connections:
+1V8: C3.1, C5.1, U2.12, U2.37, U2.49, U2.64
+3V3: C2.1, C6.1, C7.1, C8.1, C9.1, R2.2, U1.5, U2.4, U2.9, U2.20, U2.31, U2.42, U2.50, U2.56, U3.1, U3.4
/OSCI: U2.2, U3.3
/REF: R1.1, U2.6
/RESET: R2.1, U2.14
D+: J1.3, U2.8
D-: J1.2, U2.7
DTR#: Q1.1, Q2.2, U2.21
EN: J2.6, Q1.3
GND: C1.2, C2.2, C3.2, C5.2, C6.2, C7.2, C8.2, C9.2, J1.5, J1.6, J2.10, R1.2, U1.2, U2.1, U2.5, U2.10, U2.11, U2.13, U2.15, U2.25, U2.35, U2.47, U2.51, U3.2
IO0: J2.8, Q2.3
unnamed: D1.1, R3.1
unnamed: D2.1, R4.1
RTS#: Q1.2, Q2.1, U2.18
RX: J2.4, U2.17
RXLED#: R4.2, U2.29
TCK: J2.5, U2.38
TDI: J2.3, U2.39
TDO: J2.7, U2.40
TMS: J2.1, U2.41
TX: J2.2, U2.16
TXLED#: R3.2, U2.30
VBUS: C1.1, D1.2, D2.2, J1.1, U1.1, U1.3

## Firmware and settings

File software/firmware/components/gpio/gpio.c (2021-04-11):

#include "gpio.h"
#include "error.h"
#include "events.h"
#include "flash.h"
#include "dns.h"
#include "error.h"
#include "ota.h"
#include "freertos/FreeRTOS.h"
#include "freertos/task.h"
#include "freertos/queue.h"
#include "driver/gpio.h"
#include "driver/ledc.h"

#define LOG_LOCAL_LEVEL ESP_LOG_INFO
#include "esp_log.h"
static const char *TAG = "GPIO";

// Define common colors

#define PURPLE      148,0,211
#define BLUE        0,0,255
#define WEAK_BLUE   0,0,60
#define GREEN       0,255,0
#define RED         255,0,0
#define YELLOW      255,255,0

#define LED_SPEED_MODE LEDC_LOW_SPEED_MODE      // LED PWM speed mode
#define MAX_DUTY_CYCLE 1023                     // Duty cycle, picked 1023 so 0-255 values can be used for color 
#define FADE_TIME 1000                          // Fade time of 1 second

#define RED_LED_CHANNEL LEDC_CHANNEL_0          // Red LED Channel
#define GREEN_LED_CHANNEL LEDC_CHANNEL_1        // Green LED Channel
#define BLUE_LED_CHANNEL LEDC_CHANNEL_2         // Blue LED Channel

static bool gpio_enabled = true;                // GPIO enabled status
static int button = -1;                         // Button GPIO
static int red_led = -1;                        // Red LED GPIO
static int green_led = -1;                      // Green LED GPIO
static int blue_led = -1;                       // Blue LED GPIO

static TaskHandle_t button_task_handle;         // Task handle for button listening task
static TaskHandle_t led_task_handle;            // Task handle for LED task

static void button_state_change(void* arg)      // Button interrupt handler 
{
    xTaskNotifyFromISR(button_task_handle, 0, eNoAction, NULL);
}

static void button_task(void* args)             // Task keeping track of time between button presses
{
    uint32_t press_timestamp = 0xFFFFFFFF;
    uint32_t length = 0;

    while(1)
    {
        xTaskNotifyWait(0, 0, NULL, portMAX_DELAY);
        ESP_LOGD(TAG, "Reset Pin intr, val: %d\n", gpio_get_level(button));

        if(gpio_get_level(button) == 0) // Button is pressed down
        {
            press_timestamp = esp_log_timestamp();
        }
        else    // Button is released
        {
            length = esp_log_timestamp() - press_timestamp;
            if( length > 5000 )
            {
                ESP_LOGW(TAG, "Resetting device");
                reset_device();
                esp_restart();
            }
            else if( length > 10000 )
            {
                ESP_LOGW(TAG, "Rolling back");
                rollback_ota();
                esp_restart();
            }
            else
            {
                toggle_bit(BLOCKING_BIT);
            }
        }
    }
}

static esp_err_t set_rgb(uint8_t red, uint8_t green, uint8_t blue)
{
    // ledc_set_fade_with_time(LED_SPEED_MODE, RED_LED_CHANNEL, red*4, FADE_TIME);
    // ledc_fade_start(LED_SPEED_MODE, RED_LED_CHANNEL, LEDC_FADE_NO_WAIT);
    ledc_set_duty(LED_SPEED_MODE, RED_LED_CHANNEL, red*4);
    ledc_update_duty(LED_SPEED_MODE, RED_LED_CHANNEL);

    // ledc_set_fade_with_time(LED_SPEED_MODE, GREEN_LED_CHANNEL, green*4, FADE_TIME);
    // ledc_fade_start(LED_SPEED_MODE, GREEN_LED_CHANNEL, LEDC_FADE_NO_WAIT);
    ledc_set_duty(LED_SPEED_MODE, GREEN_LED_CHANNEL, green*4);
    ledc_update_duty(LED_SPEED_MODE, GREEN_LED_CHANNEL);

    // ledc_set_fade_with_time(LED_SPEED_MODE, BLUE_LED_CHANNEL, blue*4, FADE_TIME);
    // ledc_fade_start(LED_SPEED_MODE, BLUE_LED_CHANNEL, LEDC_FADE_NO_WAIT);
    ledc_set_duty(LED_SPEED_MODE, BLUE_LED_CHANNEL, blue*4);
    ledc_update_duty(LED_SPEED_MODE, BLUE_LED_CHANNEL);

    return ESP_OK;
}

TaskHandle_t getLEDTaskHandle()
{
    return led_task_handle;
}

static void led_task(void* args)
{
    ESP_LOGI(TAG, "Listening for events");

    uint32_t state = 0;
    while(1)
    {
        xTaskNotifyWait(0, 0, &state, portMAX_DELAY);
        
        if( check_bit(ERROR_BIT) )
        {
            set_rgb(RED);
        }
        else if( check_bit(INITIALIZING_BIT) )
        {
            set_rgb(PURPLE);
        }
        else if( check_bit(PROVISIONING_BIT) )
        {
            set_rgb(GREEN);
        }
        else if( check_bit(BLOCKING_BIT) )
        {
            set_rgb(BLUE);
        }
        else 
        {
            set_rgb(WEAK_BLUE);
        }
    }
}
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

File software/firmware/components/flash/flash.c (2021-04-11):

#include "flash.h"
#include "error.h"
#include "url.h"
#include "wifi.h"
#include "logging.h"
#include "esp_system.h"
#include "string.h"
#include "nvs_flash.h"
#include "esp_spiffs.h"
#include "esp_netif.h"
#include "lwip/inet.h"
#include "esp_wifi.h"

#define LOG_LOCAL_LEVEL ESP_LOG_INFO
#include "esp_log.h"
static const char *TAG = "FLASH";

static nvs_handle nvs;

esp_err_t get_upstream_dns(char* str)
{
    size_t length = IP4ADDR_STRLEN_MAX;
    ERROR_CHECK(nvs_get_str(nvs, "upstream_server", str, &length))
    return ESP_OK;
}

esp_err_t set_upstream_dns(char* str)
{
    ERROR_CHECK(nvs_set_str(nvs, "upstream_server", str))
    return ESP_OK;
}

esp_err_t get_device_url(char* str)
{
    size_t length = MAX_URL_LENGTH;
    ERROR_CHECK(nvs_get_str(nvs, "url", str, &length))
    return ESP_OK;
}

esp_err_t set_device_url(char* str)
{
    ERROR_CHECK(nvs_set_str(nvs, "url", str))
    return ESP_OK;
}

esp_err_t get_update_url(char* str)
{
    size_t length = MAX_URL_LENGTH;
    ERROR_CHECK(nvs_get_str(nvs, "update_url", str, &length))
    return ESP_OK;
}

esp_err_t set_update_url(char* str)
{
    ERROR_CHECK(nvs_set_str(nvs, "update_url", str))
    return ESP_OK;
}

esp_err_t get_network_info(esp_netif_ip_info_t* info)
{
    size_t length = sizeof(*info);
    esp_err_t err = nvs_get_blob(nvs, "network_info", (void*)info, &length);
    if( err != ESP_OK ){
        ESP_LOGE(TAG, "Error getting network info (%s)", esp_err_to_name(err));
    }
    return err;
}

esp_err_t set_network_info(esp_netif_ip_info_t info)
{
    esp_err_t err = nvs_set_blob(nvs, "network_info", (void*)&info, sizeof(info));
    if( err != ESP_OK ){
        ESP_LOGE(TAG, "Error setting network info (%s)", esp_err_to_name(err));
    }
    return err;
}

esp_err_t get_log_data(uint16_t* head, bool* full){
    esp_err_t err = nvs_get_u16(nvs, "log_head", head);
    err |= nvs_get_u8(nvs, "full_flag", (uint8_t*)full);

    if( err != ESP_OK ){
        return ESP_FAIL;
    }
    return ESP_OK;
}

esp_err_t update_log_data(uint16_t head, bool full)
{
    esp_err_t err = nvs_set_u16(nvs, "log_head", head);
    err |= nvs_set_u8(nvs, "full_flag", (uint8_t)full);

    if( err != ESP_OK ){
        return ESP_FAIL;
    }
    return ESP_OK;
}

esp_err_t get_enabled_interfaces(bool* eth, bool* wifi)
{
    ERROR_CHECK(nvs_get_u8(nvs, "ethernet", (uint8_t*)eth))
    ERROR_CHECK(nvs_get_u8(nvs, "wifi", (uint8_t*)wifi))
    return ESP_OK;
}

esp_err_t get_ethernet_phy_config(uint32_t* phy, uint32_t* addr, uint32_t* rst, uint32_t* mdc, uint32_t* mdio)
{
    ERROR_CHECK(nvs_get_u32(nvs, "phy", phy))
    ERROR_CHECK(nvs_get_u32(nvs, "phy_addr", addr))
    ERROR_CHECK(nvs_get_u32(nvs, "phy_rst", rst))
    ERROR_CHECK(nvs_get_u32(nvs, "phy_mdc", mdc))
    ERROR_CHECK(nvs_get_u32(nvs, "phy_mdio", mdio))
    return ESP_OK;
}

esp_err_t get_gpio_config(bool* enabled, int* button, int* red, int* green, int* blue)
{
    ERROR_CHECK(nvs_get_i8(nvs, "gpio", (int8_t*)enabled))
    ERROR_CHECK(nvs_get_i32(nvs, "button", button))
    ERROR_CHECK(nvs_get_i32(nvs, "red_led", red))
    ERROR_CHECK(nvs_get_i32(nvs, "green_led", green))
    ERROR_CHECK(nvs_get_i32(nvs, "blue_led", blue))

    return ESP_OK;
}

esp_err_t get_provisioning_status(bool* provisioned)
{
    ERROR_CHECK(nvs_get_u8(nvs, "provisioned", (uint8_t*)provisioned))
    return ESP_OK;
}

esp_err_t set_provisioning_status(bool provisioned)
{
    ERROR_CHECK(nvs_set_u8(nvs, "provisioned", (uint8_t)provisioned))
    return ESP_OK;
}

static esp_err_t init_settings()
{
    ESP_LOGI(TAG, "Saving Settings");
#if CONFIG_UPSTREAM_DNS_GOOGLE
    ERROR_CHECK(nvs_set_str(nvs, "upstream_server", GOOGLE_IP, IP4_STRLEN_MAX))
#elif CONFIG_UPSTREAM_DNS_CLOUDFARE
    ERROR_CHECK(nvs_set_str(nvs, "upstream_server", CLOUDFARE_IP))
#elif CONFIG_UPSTREAM_DNS_OPENDNS
    ERROR_CHECK(nvs_set_str(nvs, "upstream_server", OPENDNS_IP, IP4_STRLEN_MAX))
#elif CONFIG_UPSTREAM_DNS_ADGUARD
    ERROR_CHECK(nvs_set_str(nvs, "upstream_server", ADGUARD_IP, IP4_STRLEN_MAX))
#endif
    ERROR_CHECK(nvs_set_str(nvs, "url", CONFIG_DEFAULT_DEVICE_URL))
    ERROR_CHECK(nvs_set_str(nvs, "update_url", CONFIG_DEFAULT_UPDATE_URI))
    return ESP_OK;
}

static esp_err_t init_interfaces()
{
    ESP_LOGI(TAG, "Saving Interface Configuration");
    
#ifdef CONFIG_ETHERNET_ENABLE
    ERROR_CHECK(nvs_set_u8(nvs, "ethernet", true))
    ERROR_CHECK(nvs_set_u32(nvs, "phy_addr", CONFIG_ETH_PHY_ADDR))
    ERROR_CHECK(nvs_set_u32(nvs, "phy_rst", CONFIG_ETH_PHY_RST_GPIO))
    ERROR_CHECK(nvs_set_u32(nvs, "phy_mdc", CONFIG_ETH_MDC_GPIO))
    ERROR_CHECK(nvs_set_u32(nvs, "phy_mdio", CONFIG_ETH_MDIO_GPIO))
#ifdef CONFIG_ETH_PHY_LAN8720
    ERROR_CHECK(nvs_set_u32(nvs, "phy", 1))
#elif CONFIG_ETH_PHY_IP101
    ERROR_CHECK(nvs_set_u32(nvs, "phy", 2))
#elif CONFIG_ETH_PHY_RTL8201
    ERROR_CHECK(nvs_set_u32(nvs, "phy", 3))
#elif CONFIG_ETH_PHY_DP83848
    ERROR_CHECK(nvs_set_u32(nvs, "phy", 4))
#endif
#else
    ERROR_CHECK(nvs_set_u8(nvs, "ethernet", false))
    ERROR_CHECK(nvs_set_u32(nvs, "phy", 0))
    ERROR_CHECK(nvs_set_u32(nvs, "phy_addr", 0))
    ERROR_CHECK(nvs_set_u32(nvs, "phy_rst", 0))
    ERROR_CHECK(nvs_set_u32(nvs, "phy_mdc", 0))
    ERROR_CHECK(nvs_set_u32(nvs, "phy_mdio", 0))
#endif

#ifdef CONFIG_WIFI_ENABLE
    ERROR_CHECK(nvs_set_u8(nvs, "wifi", true))
#else
    ERROR_CHECK(nvs_set_u8(nvs, "wifi", false))
#endif

    // Initialize network info to 0
    esp_netif_ip_info_t info = {0};
    ERROR_CHECK(set_network_info(info))
    ERROR_CHECK(nvs_set_u8(nvs, "provisioned", false))

    return ESP_OK;
}

static esp_err_t init_gpio()
{
    ESP_LOGI(TAG, "Saving GPIO Configuration");
#ifdef CONFIG_GPIO_ENABLE
    ERROR_CHECK(nvs_set_i8(nvs, "gpio", true))
    ERROR_CHECK(nvs_set_i32(nvs, "button", CONFIG_BUTTON))
    ERROR_CHECK(nvs_set_i32(nvs, "red_led", CONFIG_RED_LED))
    ERROR_CHECK(nvs_set_i32(nvs, "green_led", CONFIG_GREEN_LED))
    ERROR_CHECK(nvs_set_i32(nvs, "blue_led", CONFIG_BLUE_LED))
#else
    ERROR_CHECK(nvs_set_i8(nvs, "gpio", false))
    ERROR_CHECK(nvs_set_i32(nvs, "button", -1))
    ERROR_CHECK(nvs_set_i32(nvs, "red_led", -1))
    ERROR_CHECK(nvs_set_i32(nvs, "green_led", -1))
    ERROR_CHECK(nvs_set_i32(nvs, "blue_led", -1))
#endif

    return ESP_OK;
}

static esp_err_t first_power_on()
{
    ESP_LOGI(TAG, "First power up");
    ERROR_CHECK(init_settings())
    ERROR_CHECK(init_interfaces())
    ERROR_CHECK(init_gpio())
    ERROR_CHECK(create_log_file())
    ERROR_CHECK(store_default_blacklists())

    ERROR_CHECK(nvs_set_u8(nvs, "initialized", (uint8_t)true))
    
    return ESP_OK;
}

esp_err_t reset_device()
{
    ESP_LOGI(TAG, "Resetting Device");
    ERROR_CHECK(nvs_set_u8(nvs, "provisioned", (uint8_t)false))
    return ESP_OK;
}
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

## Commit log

2021-01-24 Combined all repos into one
    [ESP32.sch, Enclosure.FCStd, EnclosureBottom.stl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]
2021-02-10 Updated webserver to use JSON, and ota over http
    [configuration.h]
2021-02-10 Fixed blocking button
2021-02-22 Add menuconfig configuration options to support dev boards
    [configuration.h]
2021-02-23 refactoring flash.c
    [partitions_table.csv]
2021-02-23 Still working on configuration options, also added error component
    [flash.c]
2021-02-25 Integrating new netif files with the rest of the application
    [configuration.h]
2021-02-26 Finished move over to new netif component, added new event component
    [configuration.h]
2021-03-07 Starting up GPIO/LED stuff
2021-03-17 Close to feature complete, need to add documentation and run through tests
    [configuration.h]
2021-03-17 Changed some permissions and updated build script
    [log.csv, partitions_table.csv]
2021-03-26 Added more error handling to DNS, no more receive buffer errors
    [gpio.c]
2021-03-29 Added more README
    [ESP32.sch, Enclosure.FCStd, EnclosureBottom.stl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]
2021-04-04 Fixed bug in auto-programming circuit by adding 1uf cap on EN
    [ESP32.sch, Enclosure.FCStd, EnclosureTop.stl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]
2021-04-05 Updated schematic to be more readable
    [BOM.csv, ESP32.sch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]
2021-04-06 Gitignore changes
    [programmer.kicad_pcb, programmer.sch]
2021-04-06 Renaming some stuff
    [BOM.csv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]
2021-04-06 Added fab outputs for usb esper
    [BOM.csv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]
2021-04-09 Created PDFs of schematics, updates to documentation
